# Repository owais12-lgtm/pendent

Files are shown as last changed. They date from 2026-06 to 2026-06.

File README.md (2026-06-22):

# Pendent 
this pendent uses a ESP32-C3, BME280, and SGP40, it measures temperature, humidity, air pressure, and air quality. its powered by a battery and designed to be low profile and really compact.

# Features 
ESP32-C3-WROOM-02 microcontroller
BME280 temperature, humidity, and pressure sensor
SGP40 air quality sensor
USB-C charging
LiPo battery support
Custom compact PCB
Low-power design
Push button interface
 # PCB
 


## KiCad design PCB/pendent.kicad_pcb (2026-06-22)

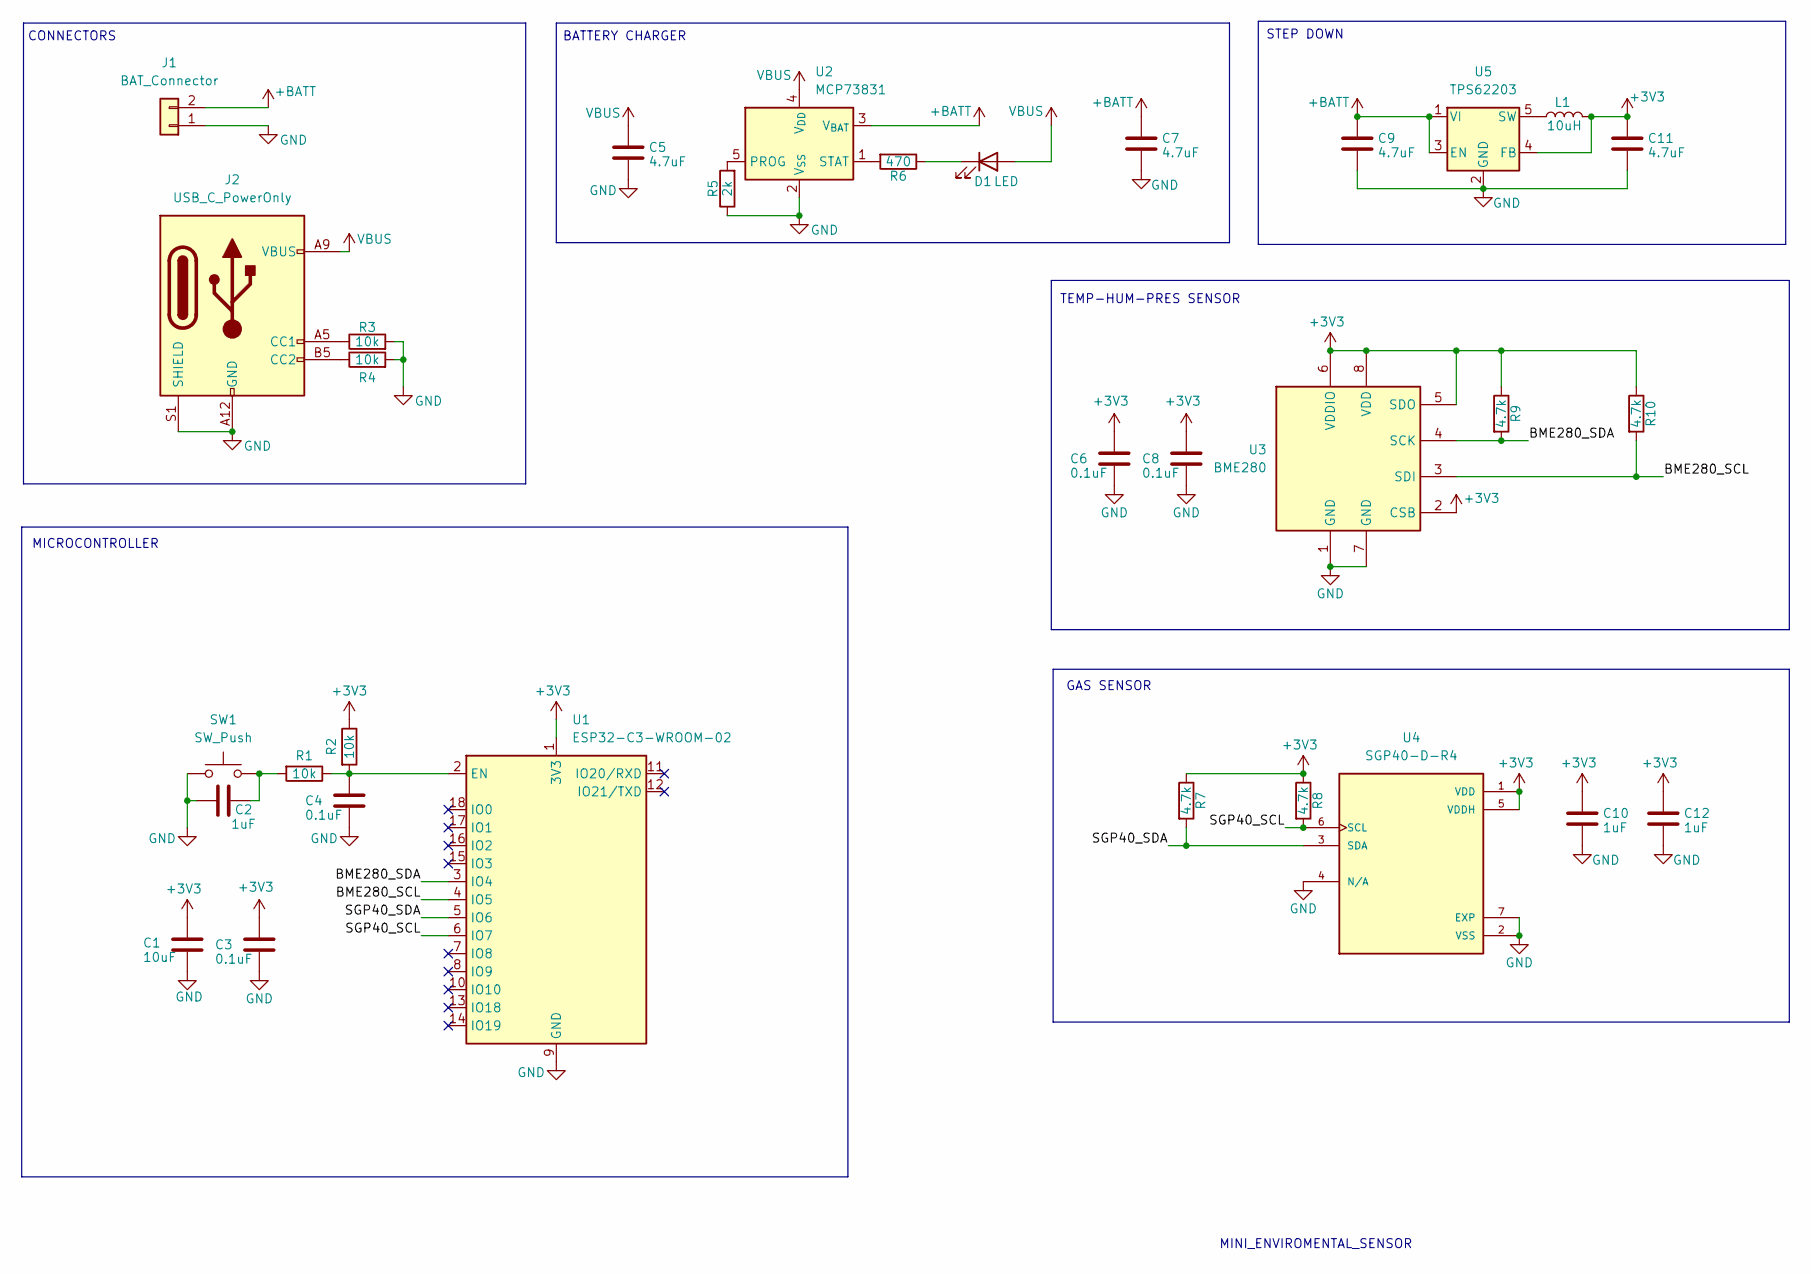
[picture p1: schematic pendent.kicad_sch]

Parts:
C1: 10uF; C_0603_1608Metric; MPN CL10A106KP8NNNC; LCSC PN C19702
C2, C10, C12: 1uF; C_0603_1608Metric; MPN SMDTC04100VA00MS00; LCSC PN C29266
C3, C4, C6, C8: 0.1uF; C_0402_1005Metric; MPN CL05B104KO5NNNC; LCSC PN C1525
C5, C7, C9, C11: 4.7uF; C_0603_1608Metric; MPN CL10A475KP8NNNC; LCSC PN C1705
D1: LED; LED_0603_1608Metric
J1: BAT_Connector; Molex_PicoBlade_53261-0271_1x02-1MP_P1.25mm_Horizontal; MPN 532610271; LCSC PN C177225
J2: USB_C_PowerOnly; USB_C_Receptacle_GCT_USB4135-GF-A_6P_TopMnt_Horizontal; MPN USB4135-GF-A; LCSC PN C5438410
L1: 10uH; L_0603_1608Metric
R1, R2, R3, R4: 10k; R_0603_1608Metric; MPN RC0603FR-0710KL; LCSC PN C98220
R5: 2k; R_0603_1608Metric; MPN RC0603FR-072KL; LCSC PN C105576
R6: 470; R_0402_1005Metric; MPN 0402WGF4700TCE; LCSC PN C25117
R7, R8, R9, R10: 4.7k; R_0603_1608Metric; MPN RC0603FR-074K7L; LCSC PN C99782
SW1: SW_Push; SW_Push_SPST_NO_Alps_SKRK; MPN SKRKAEE020; LCSC PN C115357
U1: ESP32-C3-WROOM-02; MPN ESP32-C3-WROOM-02-N4; LCSC PN C2934560
U2: MCP73831; SOT-23-5; MPN MCP73831T-2ACI/OT; LCSC PN C424093
U3: BME280; Bosch_LGA-8_2.5x2.5mm_P0.65mm_ClockwisePinNumbering; MPN BME280; LCSC PN C92489
U4: SGP40-D-R4; XCDR_SGP40-D-R4; MPN SGP40-D-R4
U5: TPS62203; SOT-23-5; MPN TPS62203DBVR; LCSC PN C9051

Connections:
+3V3: C1.1, C3.1, C6.1, C8.1, C10.1, C11.1, C12.1, L1.2, R2.1, R7.1, R8.1, R9.1, R10.1, U1.1 (3V3), U3.2 (CSB), U3.5 (SDO), U3.6 (VDDIO), U3.8 (VDD), U4.1 (VDD), U4.5 (VDDH), U5.4 (FB)
+BATT: C7.1, C9.1, J1.2, U2.3 (V_{BAT}), U5.1 (VI), U5.3 (EN)
/BME280_SCL: R10.2, U1.4 (IO5), U3.3 (SDI)
/BME280_SDA: R9.2, U1.3 (IO4), U3.4 (SCK)
/SGP40_SCL: R8.2, U1.6 (IO7), U4.6 (SCL)
/SGP40_SDA: R7.2, U1.5 (IO6), U4.3 (SDA)
GND: C1.2, C2.2, C3.2, C4.2, C5.2, C6.2, C7.2, C8.2, C9.2, C10.2, C11.2, C12.2, J1.1, J2.A12 (GND), J2.B12 (GND), J2.S1 (SHIELD), R3.2, R4.2, R5.1, SW1.1, U1.9 (GND), U1.19 (GND), U2.2 (V_{SS}), U3.1 (GND), U3.7 (GND), U4.2 (VSS), U4.4 (N/A), U4.7 (EXP), U5.2 (GND)
unnamed: C2.1, R1.2, SW1.2
unnamed: D1.1 (K), R6.1
unnamed: J2.A5 (CC1), R3.1
unnamed: J2.B5 (CC2), R4.1
unnamed: C4.1, R1.1, R2.2, U1.2 (EN)
unnamed: R5.2, U2.5 (PROG)
unnamed: R6.2, U2.1 (STAT)
unnamed: L1.1, U5.5 (SW)
VBUS: C5.1, D1.2 (A), J2.A9 (VBUS), J2.B9 (VBUS), U2.4 (V_{DD})

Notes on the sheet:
MINI_ENVIROMENTAL_SENSOR
GAS SENSOR
BATTERY CHARGER
STEP DOWN
MICROCONTROLLER
CONNECTORS
TEMP-HUM-PRES SENSOR

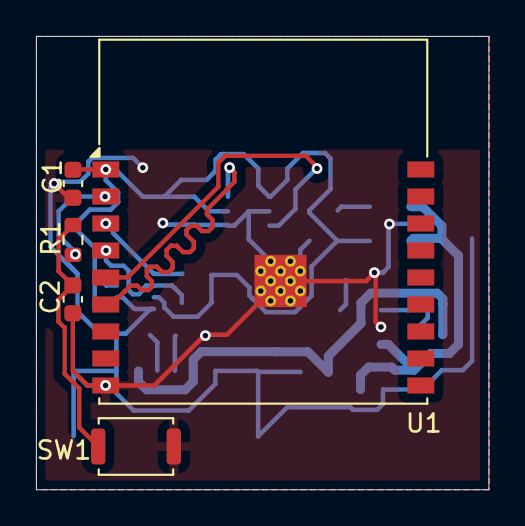
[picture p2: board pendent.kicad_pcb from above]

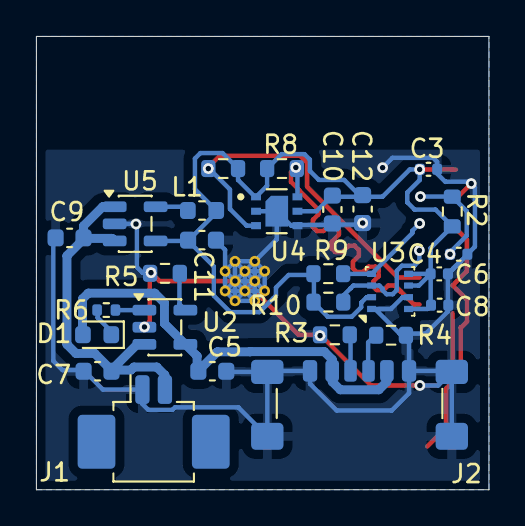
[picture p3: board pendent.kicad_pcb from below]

Board: 2 copper layers, 25.1 x 25.2 mm, 32 parts (27 on the bottom side), 16 nets.
